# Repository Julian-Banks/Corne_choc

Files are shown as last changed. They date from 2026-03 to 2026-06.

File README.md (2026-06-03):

# Corne Choc — Wireless Build

A wireless, hot-swappable Corne (crkbd) split keyboard built around Kailh Choc V2 switches and the Corne Chocoflan PCB.

## Final Build Spec

| Decision | Choice |
| --- | --- |
| **Layout** | Corne (3×6 + 3 thumb, split) |
| **PCB** | [Corne Chocoflan](https://github.com/ergomechstore/Corne-chocoflan) (wireless, choc-spaced) |
| **Switches** | Kailh Choc V2 Low Profile — White Rain, Black Cloud, Ghost  |
| **Microcontroller** | SuperMini nRF52840 (cheap Nice!Nano-compatible alternative) |
| **Wireless** | Yes (ZMK / nRF52840) |
| **OLED** | Yes — SSD1306 |
| **Hot-swap** | Yes — Kailh Choc sockets |
| **LEDs** | No (skipped to preserve battery on wireless) |
| **Keycaps** | Choc V2 blanks (surprisingly nice quality) |
| **Case** | [Wireless Corne Chocoflan minimal case](https://www.printables.com/model/1020389-wireless-corne-chocoflan-minimal-keyboard-case/files) |

## Guides & References

- **Official Corne Choc docs** — [foostan/crkbd](https://github.com/foostan/crkbd/tree/main/docs/corne-chocolate)
- **Build log inspiration** (V1 caps, no hot-swap) — [Choc Spaced Corne Wireless](https://github.com/rafaeldelboni/buildlogs/blob/main/crkbd-choc-spaced-switch.md)
- **Chocoflan build blog** — [sascha.sh: I built another mechanical keyboard](https://sascha.sh/posts/i-built-another-mechanical-keyboard/)

### Microcontroller notes
- **SuperMini nRF52840** *(chosen)* — cheap (~$3–5 each), well documented for a Chinese alternative. [Reddit overview](https://www.reddit.com/r/ErgoMechKeyboards/comments/16q5b2c/supermini_nrf52840_a_6_nicenano_20_compatible_mcu/) · [Alternatives wiki](https://github.com/joric/nrfmicro/wiki/Alternatives)
- **Nice!Nano** — the standard, well-documented option, but pricey (~$24 each + shipping).

### Switch references
- [Kailh Choc Switch Impressions](https://www.youtube.com/watch?v=mxUqfPf_1B0)
- [Kailh Choc V2 Red Low-Profile Sound Test](https://www.youtube.com/watch?v=VXPfzeLmQ5g)

### Keycap references (alternatives considered)
- [3D-print: Choc Louder keycaps (choc + MX spacing)](https://www.printables.com/model/1066117-choc-louder-keycaps-choc-and-mx-spacing/files)
- [Resin-printed low-profile caps](https://www.thingiverse.com/thing:4862025)

### Case references (alternatives considered)
- [Slim wireless Corne case](https://www.printables.com/model/416378-wireless-corne-case)
- [Carry case with travel box](https://www.printables.com/model/544127-wireless-corne-choc-v2-case-with-travel-box/files)
- [Case with OLED cover (5×3 Typeractive)](https://www.printables.com/model/441819-wireless-corne-case-5x3-typeractive)

## Bill of Materials

### Electrical Parts

| Part | Specific Part | Link | QTY | Notes |
| --- | --- | --- | --- | --- |
| Microcontroller | SuperMini nRF52840 | | 2 | Cheap alternative to the Nice!Nano |
| MCU headers | | [AliExpress](https://www.aliexpress.com/item/32896689725.html) | 10 × 40-pin (400 pins) | |
| PCB | Corne Chocoflan | [repo](https://github.com/ergomechstore/Corne-chocoflan) | 5 pairs | |
| Switches | Kailh Choc V2 Low Profile — White Rain | [AliExpress](https://www.aliexpress.com/item/1005009022408681.html) | 90 | |
| Switches | Kailh Choc V2 Low Profile — Black Cloud | [AliExpress](https://www.aliexpress.com/item/1005009022408681.html) | 90 | |
| Switches | Kailh Choc V2 Low Profile — Ghost | [AliExpress](https://www.aliexpress.com/item/1005007404357477.html) | 90 | |
| Hot-swap sockets | Kailh Choc sockets | [AliExpress](https://www.aliexpress.com/item/1005008954571807.html) | 220 | |
| Keycaps | Choc V2 blanks | [AliExpress](https://www.aliexpress.com/item/1005009100305250.html) | 220 | Nicer quality than expected |
| Diodes | 1N4148W SMD | [AliExpress](https://www.aliexpress.com/item/32921490945.html) | | |
| OLED display | SSD1306 | [AliExpress](https://www.aliexpress.com/item/1005008640132638.html) | 10 | |
| On/off switch | | [AliExpress](https://www.aliexpress.com/item/1005003829889015.html) | 20 | |
| Reset buttons | Momentary push buttons | [AliExpress](https://www.aliexpress.com/item/1005002201965659.html) | 100 | |
| Battery | LiPo 3.7V 120mAh (PH2.0 connector) | [DIY Electronics](https://www.diyelectronics.co.za/store/li-ion-li-po/6707-lipo-battery-37v-120mah-25x24x35mm-1c-1cell-with-ph20-connector.html) | 2 | |

### Mechanical Parts

Driven by the Chocoflan PCB and the minimal case choice.

| Part | Specific Part | Link | QTY | Notes |
| --- | --- | --- | --- | --- |
| Case | Wireless Corne Chocoflan minimal case | [Printables](https://www.printables.com/model/1020389-wireless-corne-chocoflan-minimal-keyboard-case/files) | 1 set | 3D printed |
| Bottom Plate  | See `plate_cut*.dxf` / `.svg` in repo  | | | lazer cut from Aluminimum |
| Switch plate | See `plate_cut*.dxf` / `.svg` in repo  | | | lazer cut from Aluminimum |
| Standoffs + screws | | | | |
| PK-662 tenting stands | | | | |

## Firmware Setup & Configuration

This board runs [ZMK](https://zmk.dev). Firmware is built in the cloud by GitHub Actions — no local toolchain needed. Full guide: [zmk.dev/docs/user-setup](https://zmk.dev/docs/user-setup).

**Setup (once):**
1. Run the ZMK setup script (or `zmk init`) to create your config repo.
2. Choose the keyboard and controller when prompted:
   - **Keyboard / shield:** `Corne`
   - **Board:** `nice_nano_v2` (the SuperMini nRF52840 is nice!nano-compatible)
3. Push the repo to GitHub.

**Configure:**
- Keymap lives in `config/corne.keymap` — edit layers, combos, behaviors here.
- Feature flags live in `config/corne.conf` — e.g. enable the OLED and disable RGB:
  ```ini
  CONFIG_ZMK_DISPLAY=y
  # no underglow / per-key LEDs on this build
  ```

**Build & flash:**
1. `git push` → GitHub Actions builds automatically.
2. Download the `firmware` artifact from the Actions tab — it contains the `.uf2` files (one per half, plus a `settings_reset`).
3. Double-tap reset on a half to enter bootloader, then drag the matching `.uf2` onto the USB drive that appears. Repeat for the other half.

## Credits

- **PCB** — [Corne Chocoflan by ergomechstore](https://github.com/ergomechstore/Corne-chocoflan). The Gerbers and KiCad source in `PCB/` are vendored from this open-source project.
- **Layout** — [Corne (crkbd) by foostan](https://github.com/foostan/crkbd).
- **Case** — [Wireless Corne Chocoflan minimal case](https://www.printables.com/model/1020389-wireless-corne-chocoflan-minimal-keyboard-case/files).

## Repo Contents

- `PCB/` — pointer to the external Corne Chocoflan PCB design (no source vendored).
- `Laser Cutting/` — switch/plate cut files (`.dxf`, `.svg`, `.pdf`).
- `3D Prints/` — case and cover models (`.step`, `.stl`, `.f3d`), including a custom MK2 chassis and carry case explored during design.
- `images/` — build photos.
- `brainstorming.md` — original decision notes and research (kept for history).

## Build Photos

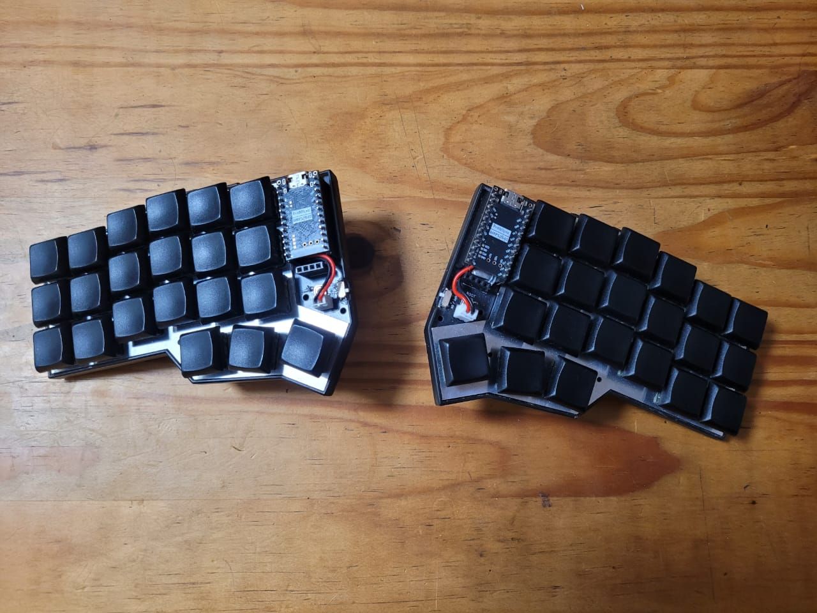
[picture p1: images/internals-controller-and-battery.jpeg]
Internals — controller and battery

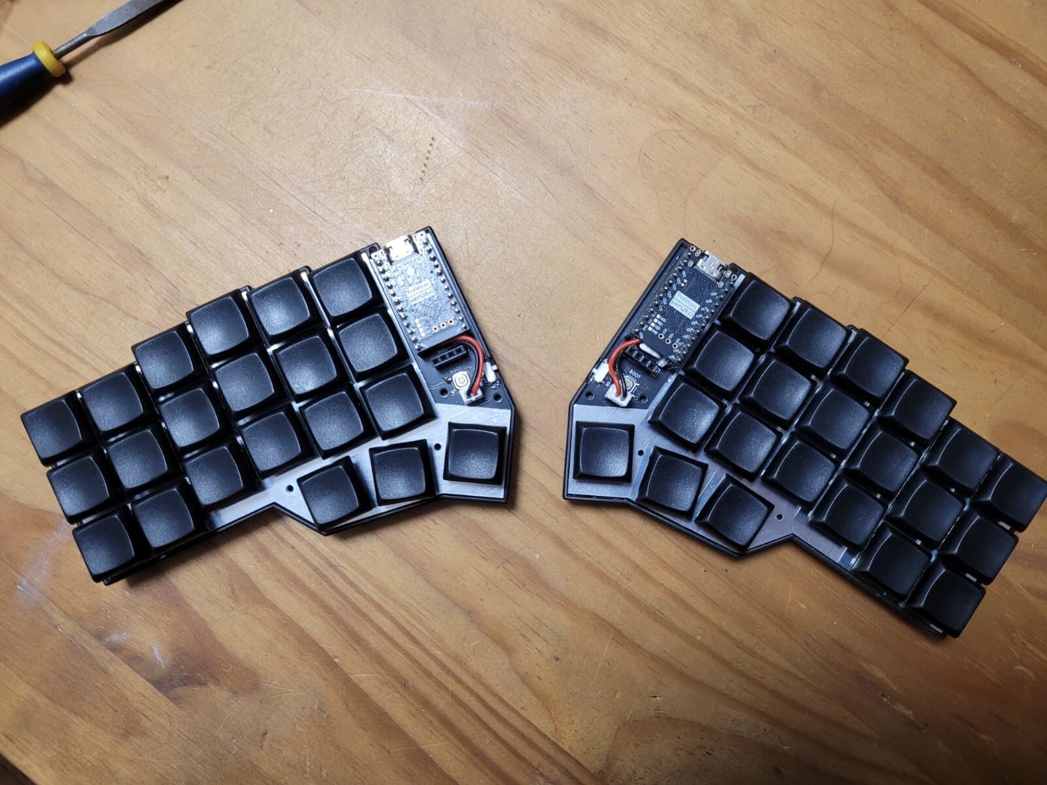
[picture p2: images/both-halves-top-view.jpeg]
Both halves, top view

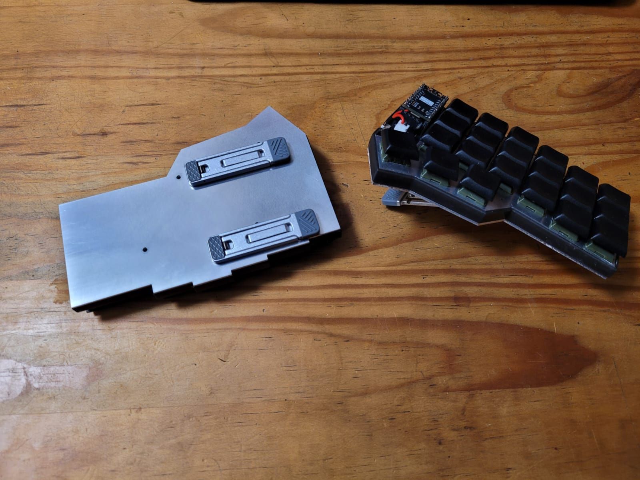
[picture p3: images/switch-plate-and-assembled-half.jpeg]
Switch plate alongside an assembled half

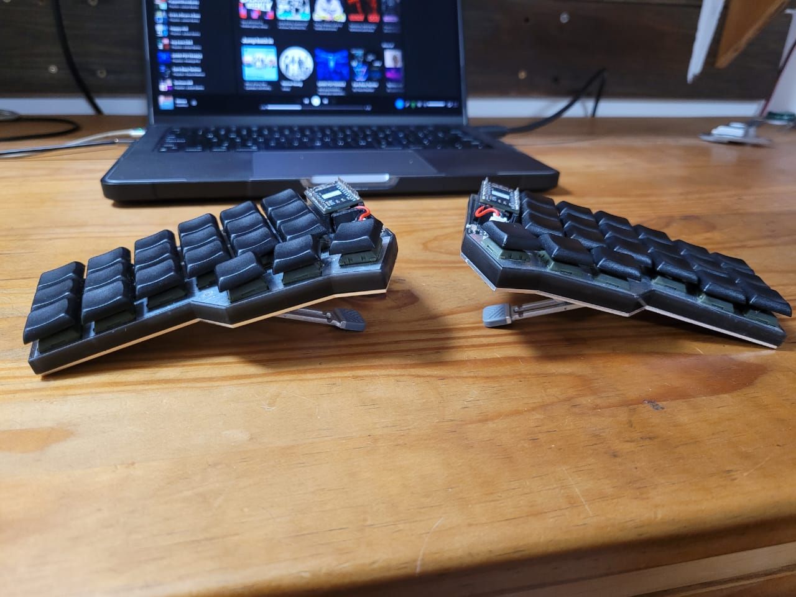
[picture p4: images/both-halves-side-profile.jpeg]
Both halves, side profile

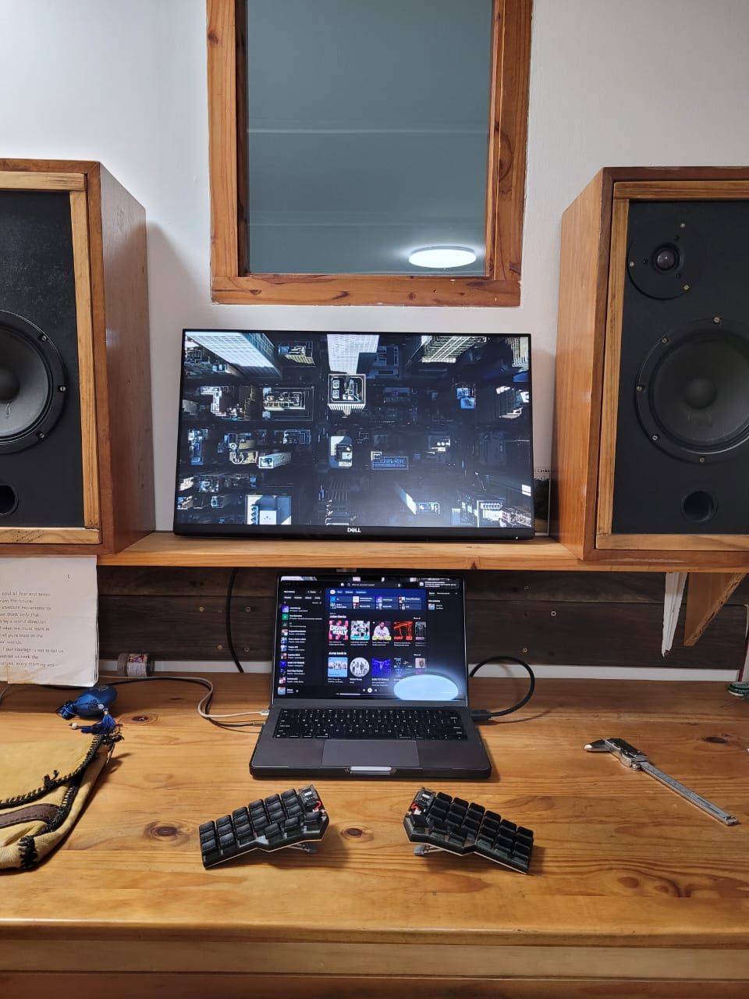
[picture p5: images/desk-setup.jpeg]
Desk setup


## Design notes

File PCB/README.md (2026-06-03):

# PCB

This build uses the **Corne Chocoflan** (rev2) wireless, choc-spaced PCB — the board that was actually fabricated for this keyboard. The design files are vendored here from the upstream open-source repo.

**Credit:** PCB design by [ergomechstore — Corne-chocoflan](https://github.com/ergomechstore/Corne-chocoflan). All design files in this folder originate from that project.

## What's here — `Corne-chocoflan/`

- `gerber/rev2/corne_chocoflan_gerbers.zip` — **production Gerbers** (upload this to JLCPCB / your fab).
- `gerber/rev2/corne_chocoflan_gerbers/` — the unzipped Gerber + drill files.
- `gerber/rev2/bom_pos/` — BOM and pick-and-place (POS) CSVs for assembly.
- `gerber/rev2/ibom.html` — interactive BOM (open in a browser for placement reference).
- `gerber/rev2/corne_chocoflan.step` — 3D model of the board.
- `pcb/rev2/` — KiCad source (`.kicad_pcb`, `.kicad_sch`, `.kicad_pro`) if you need to edit the design.

KiCad auto-save backups and `.git` history from the upstream clone were dropped to keep the repo lean.

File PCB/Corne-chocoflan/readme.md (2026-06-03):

# Corne Chocoflan PCB
An split ergonomic hotswap PCB, based on original Corne made by Foostan. Designed in KiCAD 6.99.

Renders (KiCAD):
**Revision 1**:





**Revision 2**:





## Features
**Revision 1**:
- Uses the Pro Micro and Nice!Nano.
- Uses Kailh Choc hotswap sockets.
- Split ergo layout (see below).
- Physical BOOT button for getting into bootloader.
- Slide switch to turn on and off Bluetooth mode.
- SSD1306 OLED (128x32) and Nice!View E-ink.
- Bonus: Curved traces and teardrops.

**Revision 2**:
- Remove some text on silkscreen.
- Added store logo.
- Move OLED/E-ink connector a bit higher.
- Flip the slide switches from bottom PCB to top PCB.

## Firmware
- This revision of the Corne keyboard is totally compatible with the firmware of the classic corne.

## Layout



Kits and fully built keyboards is available for purchase at https://ergomech.store

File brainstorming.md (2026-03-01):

# Alrighty where to start?

The baseline decisions: 
- **Type**: Corne
- **Switch**: Choc V2 (ghost,white rain, black cloud)
- **PCB**: [Choc spaced Wireless Corne](https://github.com/davidphilipbarr/Choc-Spaced-Corne/tree/main/chocorne-switch)  
- **Leds**: Probably not because we are going wireless
- **Wireless**: Yes 
- **OLED**: Yes 
- **Hotswap sockets**:  Yes
- **Keycaps**: Some cheap blanks

## Guides and docs
Official corne choc docs: [github docs](https://github.com/foostan/crkbd/tree/main/docs/corne-chocolate)

Build Guide inspiration (V1 keycaps, no Hotswap): [Choc Spaced Corne Keyboard - Wireless](https://github.com/rafaeldelboni/buildlogs/blob/main/crkbd-choc-spaced-switch.md)

Blog with Chocoflan board: [some dudes blog](https://sascha.sh/posts/i-built-another-mechanical-keyboard/)

### MicroController

**Nice!Nano** 
- standard option, documented and will work
- spenny ($24 each plus shipping)

**SuperMini NRF52840**
- Cheap! $3-5 each 
- Well documented as far as cheap chinese alternatives go!
- [Supermini nRF52840](https://www.reddit.com/r/ErgoMechKeyboards/comments/16q5b2c/supermini_nrf52840_a_6_nicenano_20_compatible_mcu/)
- [Alternatives (man I love nerd community)](https://github.com/joric/nrfmicro/wiki/Alternatives) 
  
### OLED
Yes just cause it's pretty freaking cool. 

### Switches 
[Kailh Choc Switch Impressions](https://www.youtube.com/watch?v=mxUqfPf_1B0)
[Kailh Choc V2 Red Low-Profile Sound Test](https://www.youtube.com/watch?v=VXPfzeLmQ5g)
I think Red makes sense, most similar to my laptop, I don't like loud keyboards. idk. 
### Keycaps
[3d Print them myself?](https://www.printables.com/model/1066117-choc-louder-keycaps-choc-and-mx-spacing/files)
Low profile and choc spaced
[3d Resin printed](https://www.thingiverse.com/thing:4862025)

### Case 
[Nice slim look](https://www.printables.com/model/416378-wireless-corne-case)

[chocoflan case](https://www.printables.com/model/1020389-wireless-corne-chocoflan-minimal-keyboard-case/files)

[Carry Case, very profess look](https://www.printables.com/model/544127-wireless-corne-choc-v2-case-with-travel-box/files)
[Has an OLED cover](https://www.printables.com/model/441819-wireless-corne-case-5x3-typeractive)

# Rough BOM 

### Electrical Parts

|Part| Specific Part | Link | QTY | Cost | Notes |
| --- | --- | ---  | --- | --- | --- |
|MicroController|  Supermini nRF52840  | |  2 |  86 (plus shipping and tax) | Cheap alternative to the Nice!Nano  |
|MicroController headers| |  [aliexpress](https://www.aliexpress.com/item/32896689725.html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) | 10*40pin = 400pins |  72 | |
|PCB|  corne chocoflan |  [repo](https://github.com/ergomechstore/Corne-chocoflan?tab=readme-ov-file) |  5 pairs | 600?  | |
|Switches|  Kailh Choc V2 Low Profile - White Rain  | [aliexpress](https://www.aliexpress.com/item/1005009022408681.html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) | 90  | 750  | |
|Switches|  Kailh Choc V2 Low Profile - Black Cloud | [aliexpress](https://www.aliexpress.com/item/1005009022408681.html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) | 90  |  750 | |
|Switches|  Kailh Choc V2 Low Profile - Ghost  | [aliexpress](https://www.aliexpress.com/item/1005007404357477.html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) |  90 | 1350  | |
|Hot Swap Sockets|  Kailh Choc sockets | [aliexpress](https://www.aliexpress.com/item/1005008954571807.html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)  | 220  |  212 | |
|Key Caps|  some cheap V2 blanks (I couldn't find PBT) | [aliexpress](https://www.aliexpress.com/item/1005009100305250.html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) |  220 | 450 | |
|Diodes| 1N4148W SMD diodes | [aliexpress](https://www.aliexpress.com/item/32921490945.html) | | | |
|OLED display| SSD1306 | [aliexpress](https://www.aliexpress.com/item/1005008640132638.html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)  | 10  | 240  | |
| On/off switch | |  [aliexpress](https://www.aliexpress.com/item/1005003829889015.html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) |  20 | 75  | |
|Reset Buttons| Momentery push buttons |  [aliexpress](https://www.aliexpress.com/item/1005002201965659.html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) | 100 |  30 | |
|Battery| | [DIY Electronics](https://www.diyelectronics.co.za/store/li-ion-li-po/6707-lipo-battery-37v-120mah-25x24x35mm-1c-1cell-with-ph20-connector.html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) | | 2  |  68 |

### Mechanical Parts
Defined based off what type of PCB I order? 

|Part| Specific Part | Link | QTY | Cost | Notes |
| --- | --- | --- | --- | --- | --- |
| Case | | | | | |
| top Plate| | | | | |
|Switch Plate| | | | | |
|Standoffs + Screws| | | | | |
|Threaded Inserts| | | | | |

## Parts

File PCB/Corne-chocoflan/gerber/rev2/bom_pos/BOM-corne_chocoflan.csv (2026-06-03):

Comment | Designator | Footprint | LCSC
DIP_L | SW1,SW3 | SW_SPDT_PCM12 | C221841
BOOT_Pin_L | SW2,SW4 | SW_SPST_TL3342 | C2886894
1N4148W_L | D1,D10,D11,D12,D13,D14,D15,D16,D17,D18,D19,D2,D20,D21,D22,D23,D24,D25,D26,D27,D28,D29,D3,D30,D31,D32,D33,D34,D35,D36,D37,D38,D39,D4,D40,D41,D42,D5,D6,D7,D8,D9 | D_SOD-123 | C81598

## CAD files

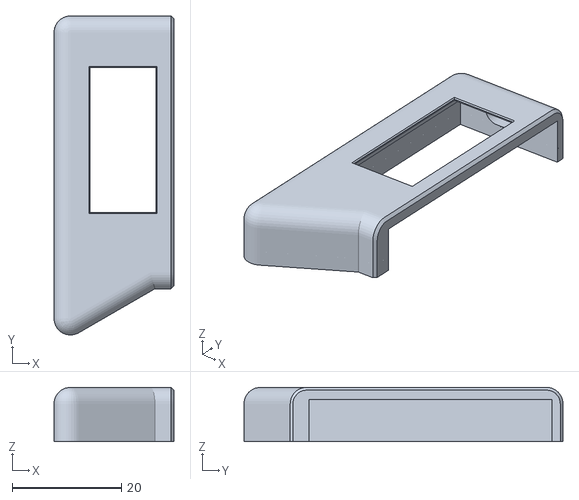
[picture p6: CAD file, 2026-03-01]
3D Prints/screen_cover_holes_fixed_extended.stl
21.9 x 58.3 x 9.90

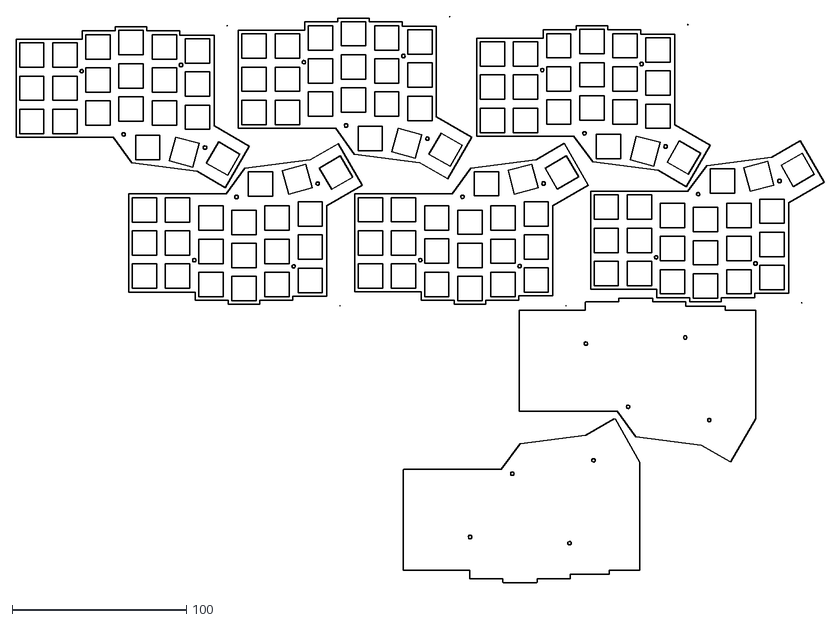
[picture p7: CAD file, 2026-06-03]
Laser Cutting/plate_cut_1.dxf
463.2 x 324.5

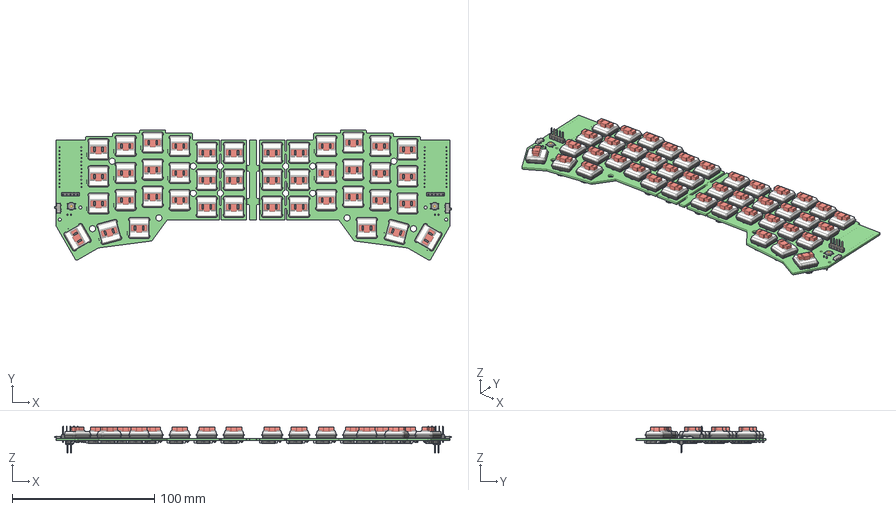
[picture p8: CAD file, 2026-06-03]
PCB/Corne-chocoflan/gerber/rev2/corne_chocoflan.step
278.7 x 91.4 x 18.8 mm
_autosave-corne_chocoflan PCB

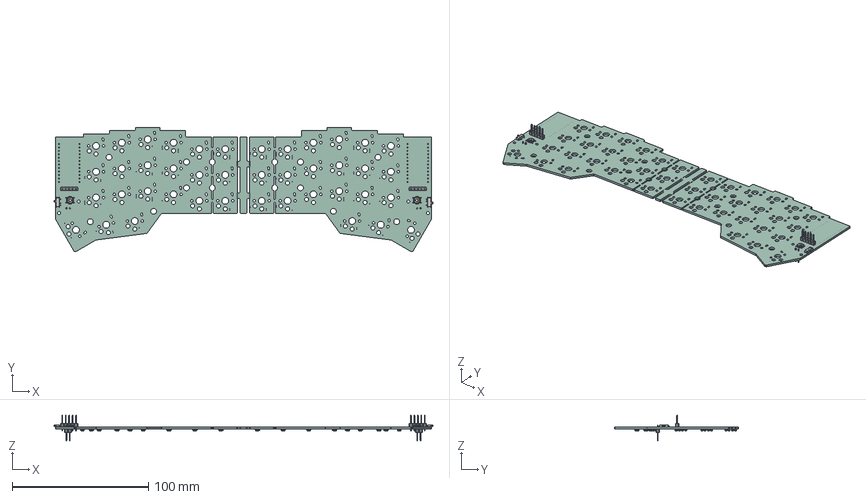
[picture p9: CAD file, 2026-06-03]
PCB/Corne-chocoflan/pcb/rev2/corne_chocoflan.step
278.7 x 91.4 x 18.8 mm
PinHeader_1x05_P2.54mm_Vertical x 2
SW_SPST_TL3342 x 2
SW_SPDT_PCM12 x 2
D_SOD-123 x 42
PinHeader_1x02_P2.54mm_Vertical x 2
corne_chocoflan_PCB

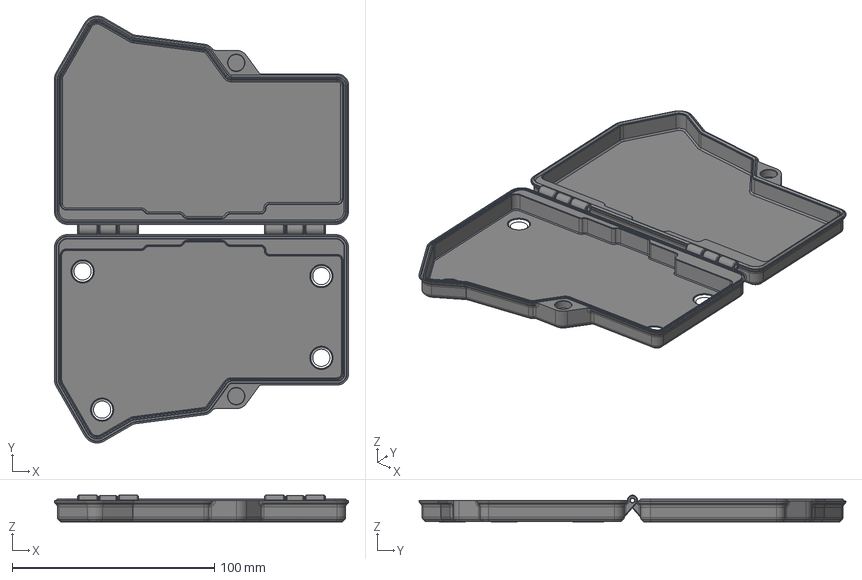
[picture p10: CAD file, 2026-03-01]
3D Prints/Corne Choc Carry Case.step
145.3 x 211.0 x 13.2 mm

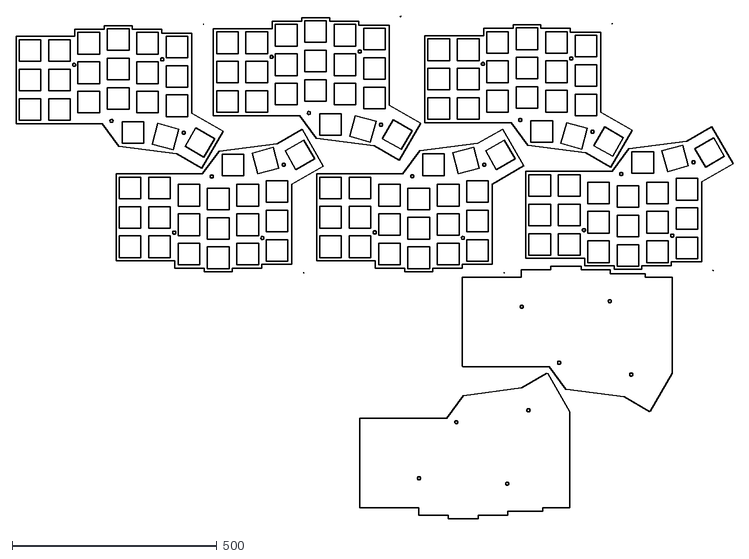
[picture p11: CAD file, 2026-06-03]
Laser Cutting/plate_cut.dxf
1750.5 x 1226.5

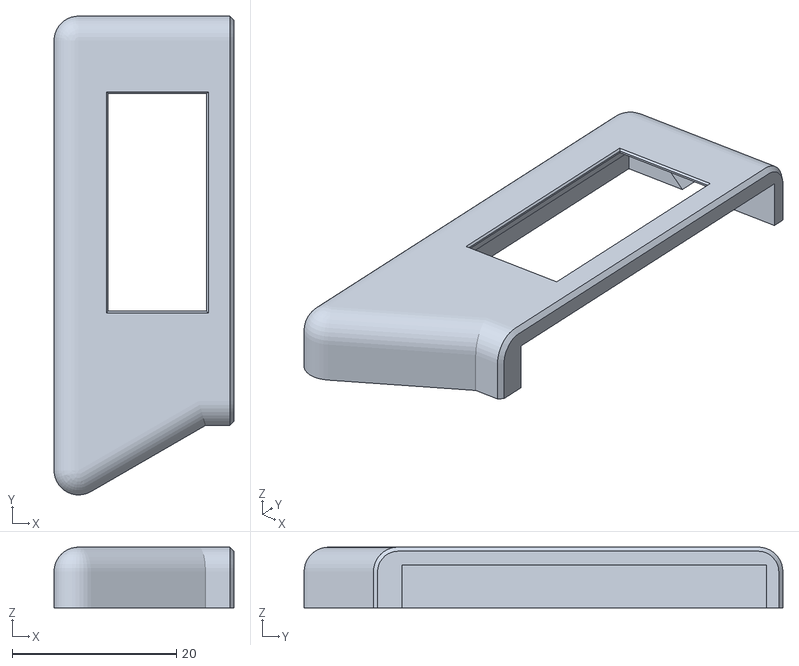
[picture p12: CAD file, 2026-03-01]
3D Prints/screen_cover_holes_fixed.stl
21.9 x 58.3 x 7.40

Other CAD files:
3D Prints/Corne Choc Case (1).f3d

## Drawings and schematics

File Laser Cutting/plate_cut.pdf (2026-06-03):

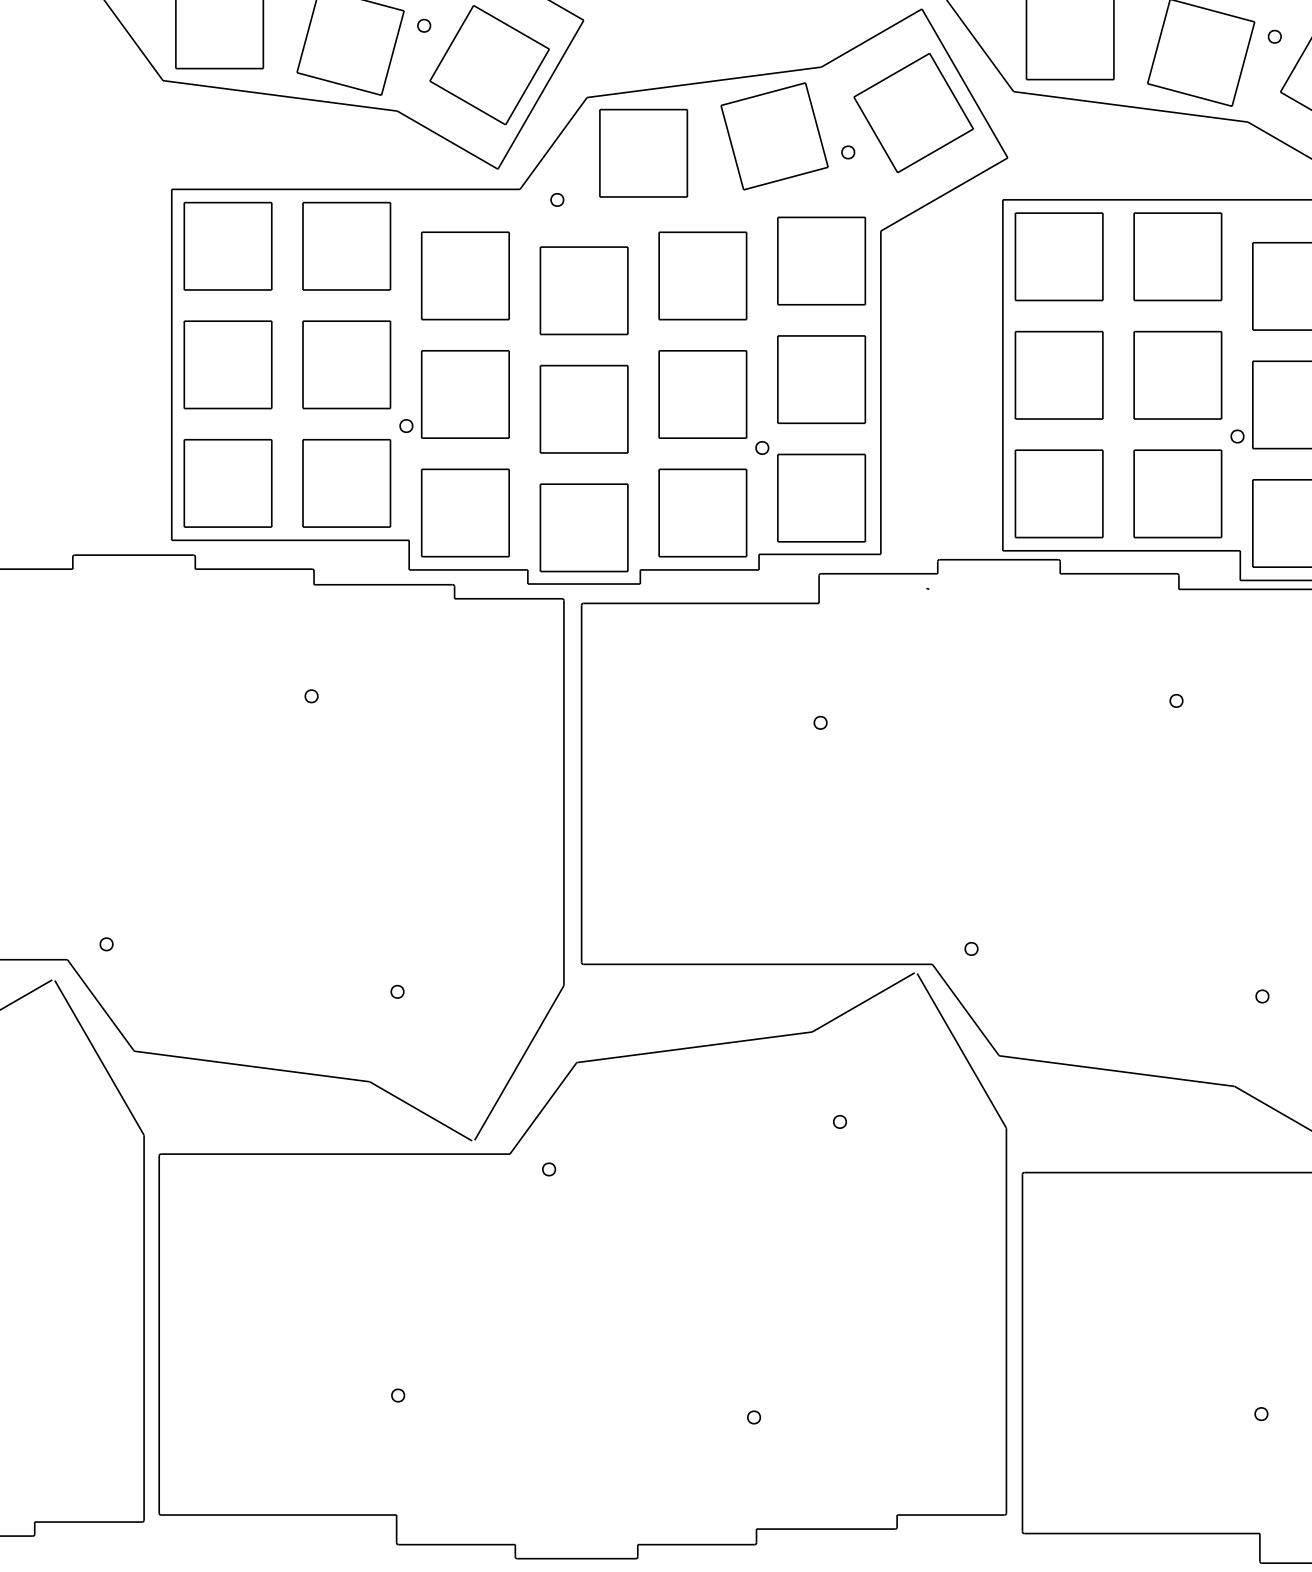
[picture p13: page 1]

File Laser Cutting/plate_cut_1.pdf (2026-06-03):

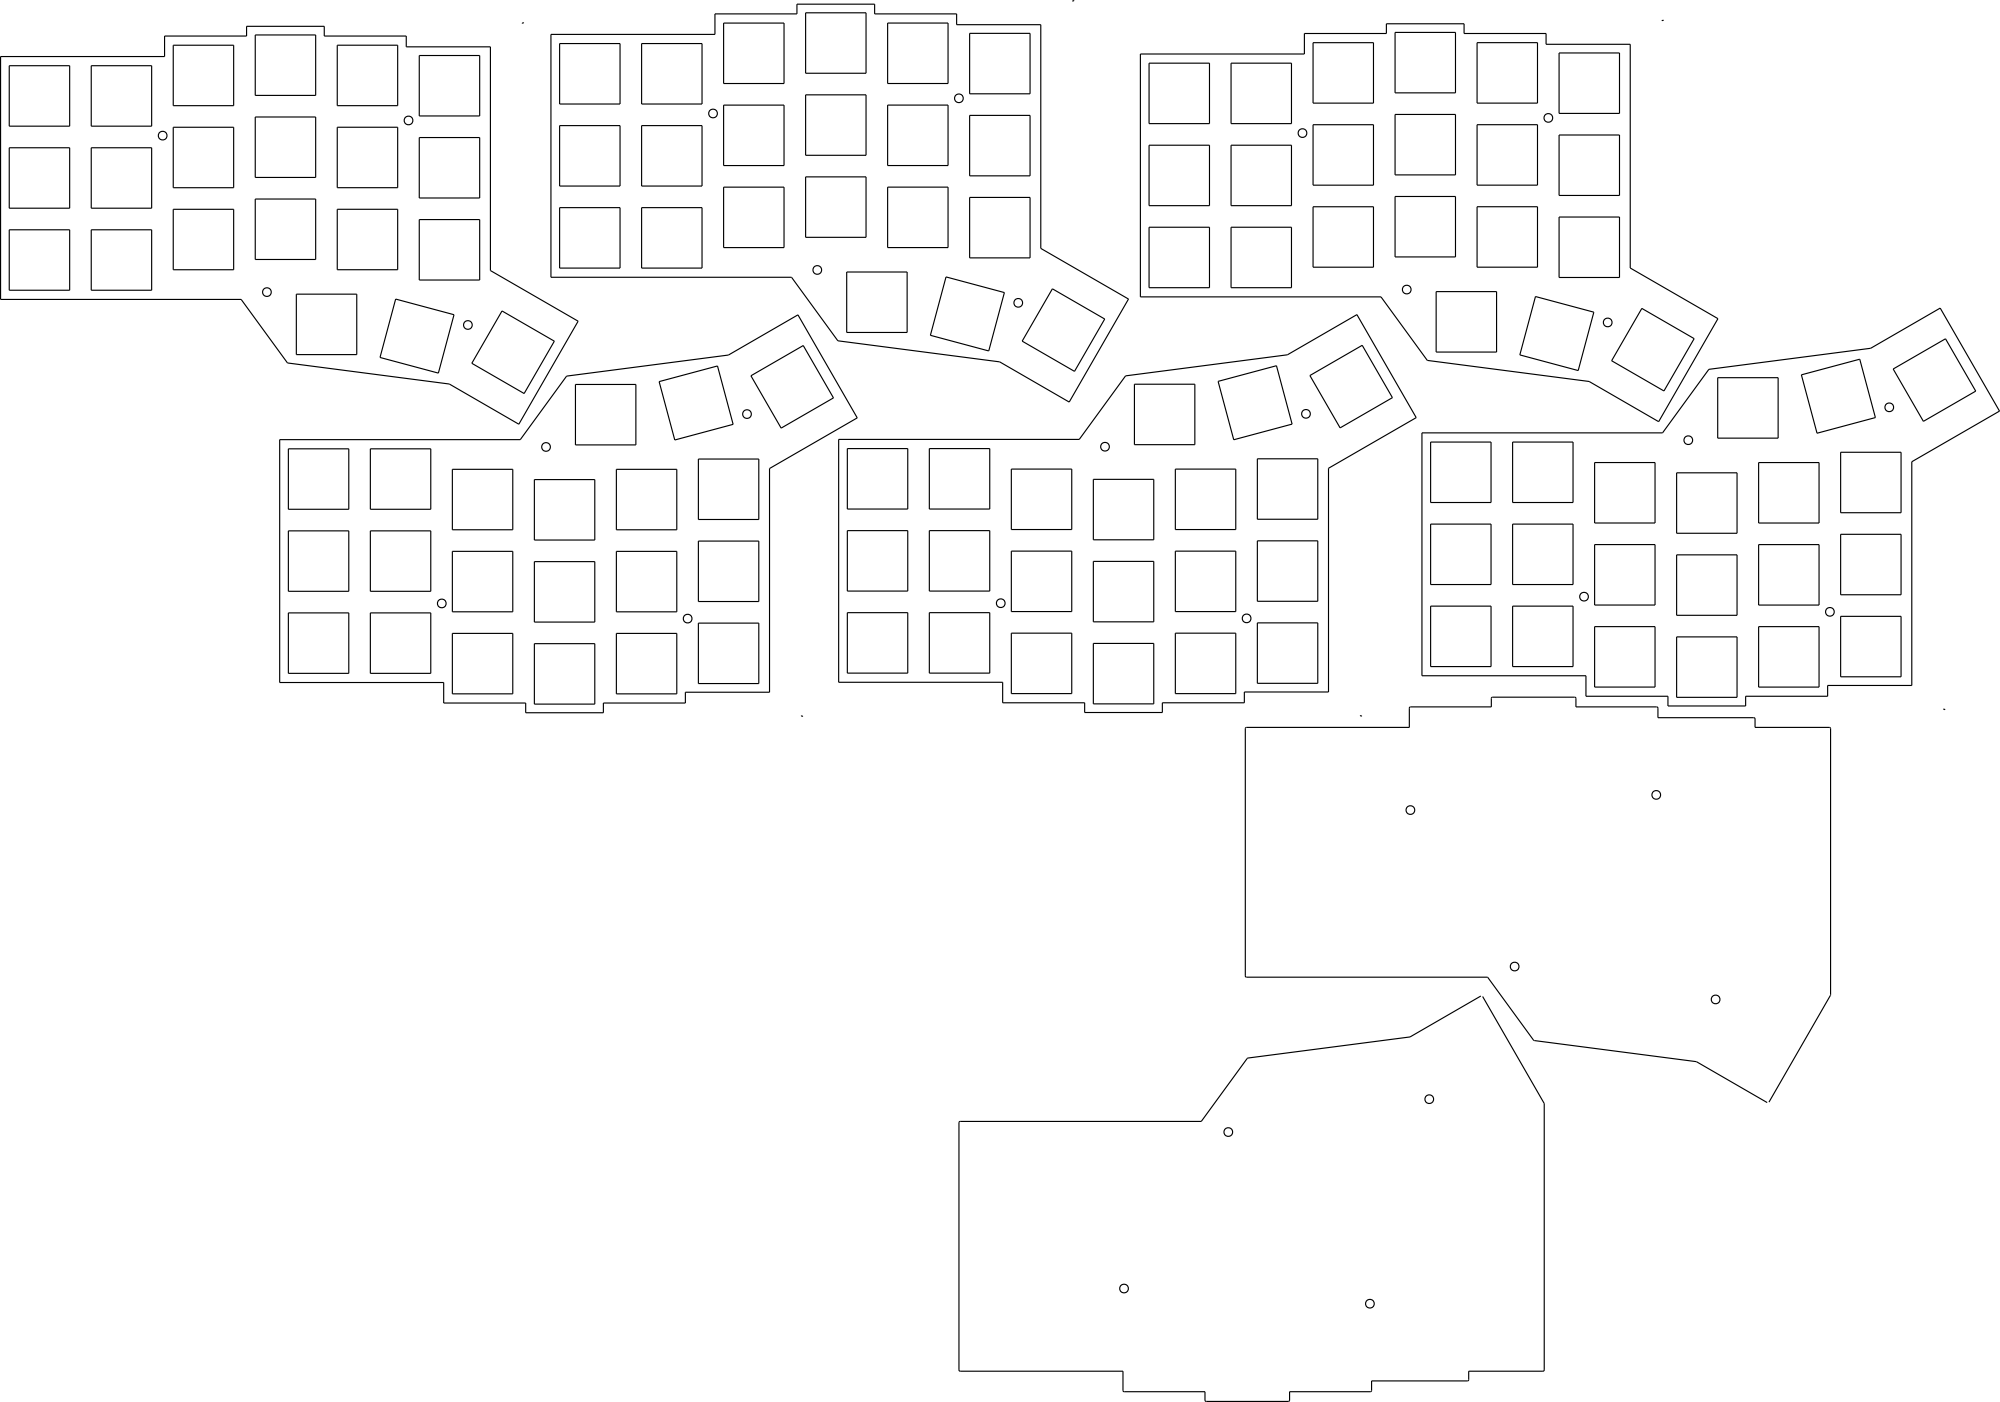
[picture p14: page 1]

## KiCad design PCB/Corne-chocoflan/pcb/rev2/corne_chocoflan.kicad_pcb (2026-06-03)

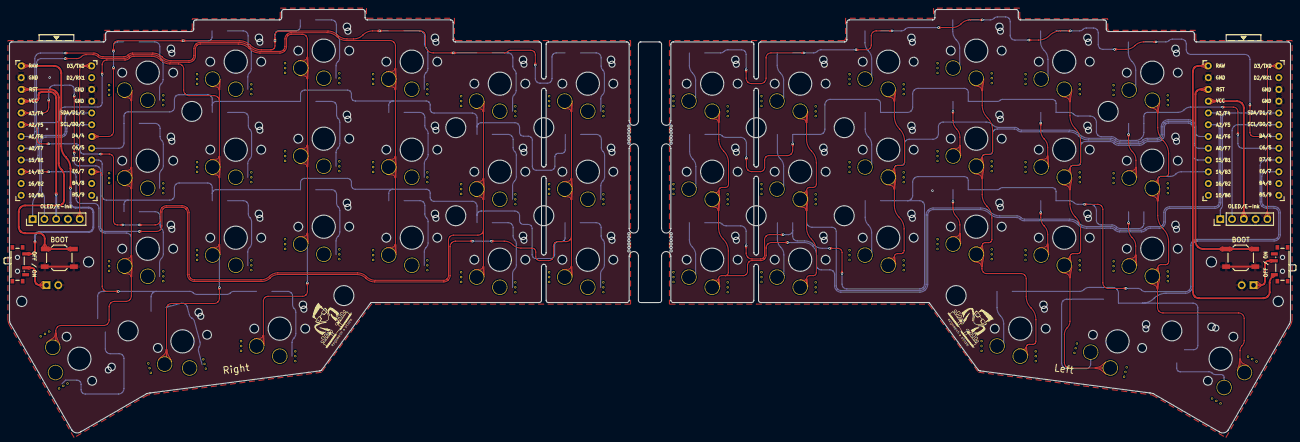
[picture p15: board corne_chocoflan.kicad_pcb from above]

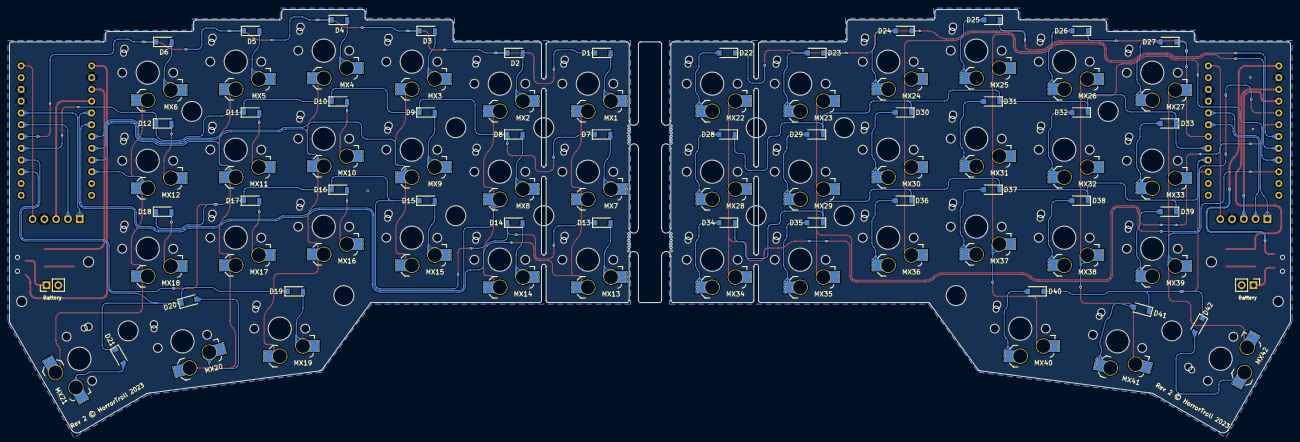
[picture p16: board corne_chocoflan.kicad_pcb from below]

Board: 2 copper layers, 276.5 x 91.4 mm, 116 parts (86 on the bottom side), 78 nets.

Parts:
D1, D2, D3, D4, D5, D6, D7, D8, D9, D10, D11, D12, D13, D14, D15, D16, D17, D18, D19, D20, D21: 1N4148W_L; D_SOD-123
D22, D23, D24, D25, D26, D27, D28, D29, D30, D31, D32, D33, D34, D35, D36, D37, D38, D39, D40, D41, D42: 1N4148W_R; D_SOD-123
J1: OLED/E-Ink_L; PinHeader_1x05_P2.54mm_Vertical
J2: Battery_L; PinHeader_1x02_P2.54mm_Vertical
J3: Battery_R; PinHeader_1x02_P2.54mm_Vertical
J4: OLED/E-Ink_R; PinHeader_1x05_P2.54mm_Vertical
M1, M2, M3, M4: Mouse_Bite; mousebites_2mm_big_width
MX1, MX2, MX3, MX4, MX5, MX6, MX7, MX8, MX9, MX10, MX11, MX12, MX13, MX14, MX15, MX16, MX17, MX18, MX19, MX20: 1u_L; SW_choc_v1_v2_HS_1u_corne
MX21: 1.5u_L; SW_choc_v1_v2_HS_1.5u_corne
MX22, MX23, MX24, MX25, MX26, MX27, MX28, MX29, MX30, MX31, MX32, MX33, MX34, MX35, MX36, MX37, MX38, MX39, MX40, MX41: 1u_R; SW_choc_v1_v2_HS_1u_corne
MX42: 1.5u_R; SW_choc_v1_v2_HS_1.5u_corne
SW1: DIP_L; SW_SPDT_PCM12
SW2: BOOT_Pin_L; SW_SPST_TL3342
SW3: DIP_R; SW_SPDT_PCM12
SW4: BOOT_Pin_R; SW_SPST_TL3342
TH1, TH2, TH3, TH4, TH5, TH6, TH7: Screw_M2_TH_L; M2_HOLE_v2
TH8, TH9: Screw_M2_PCB_L; M2_HOLE_v2_corne_2.2mm
TH10, TH11, TH12, TH13, TH14, TH15, TH16: Screw_M2_TH_R; M2_HOLE_v2
TH17, TH18: Screw_M2_PCB_R; M2_HOLE_v2_corne_2.2mm
U1: ProMicro_L; ProMicro_v3
U2: ProMicro_R; ProMicro_v3

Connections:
+3V3: J4.3, U2.21 (VCC)
BOOT_L: SW2.2, U1.22 (RST)
BOOT_R: SW4.2, U2.22 (RST)
CS_L: J1.5, U1.1 (TX0/D3)
CS_R: J4.5, U2.1 (TX0/D3)
Col0_L: MX1.2, MX7.2, MX13.2, U1.20 (F4/A3)
Col0_R: MX22.1, MX28.1, MX34.1, U2.20 (F4/A3)
Col1_L: MX2.2, MX8.2, MX14.2, U1.19 (F5/A2)
Col1_R: MX23.1, MX29.1, MX35.1, U2.19 (F5/A2)
Col2_L: MX3.2, MX9.2, MX15.2, U1.18 (F6/A1)
Col2_R: MX24.1, MX30.1, MX36.1, U2.18 (F6/A1)
Col3_L: MX4.2, MX10.2, MX16.2, MX19.2, U1.17 (F7/A0)
Col3_R: MX25.1, MX31.1, MX37.1, MX40.1, U2.17 (F7/A0)
Col4_L: MX5.2, MX11.2, MX17.2, MX20.2, U1.16 (B1/15)
Col4_R: MX26.1, MX32.1, MX38.1, MX41.1, U2.16 (B1/15)
Col5_L: MX6.2, MX12.2, MX18.2, MX21.2, U1.15 (B3/14)
Col5_R: MX27.1, MX33.1, MX39.1, MX42.1, U2.15 (B3/14)
GND: J1.4, J2.2, SW2.1, U1.3 (GND), U1.4 (GND), U1.23 (GND)
GNDA: J3.2, J4.4, SW4.1, U2.3 (GND), U2.4 (GND), U2.23 (GND)
unnamed: D1.2 (A), MX1.1
unnamed: D2.2 (A), MX2.1
unnamed: D3.2 (A), MX3.1
unnamed: D4.2 (A), MX4.1
unnamed: D5.2 (A), MX5.1
unnamed: D6.2 (A), MX6.1
unnamed: D7.2 (A), MX7.1
unnamed: D8.2 (A), MX8.1
unnamed: D9.2 (A), MX9.1
unnamed: D10.2 (A), MX10.1
unnamed: D11.2 (A), MX11.1
unnamed: D12.2 (A), MX12.1
unnamed: D13.2 (A), MX13.1
unnamed: D14.2 (A), MX14.1
unnamed: D15.2 (A), MX15.1
unnamed: D16.2 (A), MX16.1
unnamed: D17.2 (A), MX17.1
unnamed: D18.2 (A), MX18.1
unnamed: D19.2 (A), MX19.1
unnamed: D20.2 (A), MX20.1
unnamed: D21.2 (A), MX21.1
unnamed: D22.2 (A), MX22.2
unnamed: D23.2 (A), MX23.2
unnamed: D24.2 (A), MX24.2
unnamed: D25.2 (A), MX25.2
unnamed: D26.2 (A), MX26.2
unnamed: D27.2 (A), MX27.2
unnamed: D28.2 (A), MX28.2
unnamed: D29.2 (A), MX29.2
unnamed: D30.2 (A), MX30.2
unnamed: D31.2 (A), MX31.2
unnamed: D32.2 (A), MX32.2
unnamed: D33.2 (A), MX33.2
unnamed: D34.2 (A), MX34.2
unnamed: D35.2 (A), MX35.2
unnamed: D36.2 (A), MX36.2
unnamed: D37.2 (A), MX37.2
unnamed: D38.2 (A), MX38.2
unnamed: D39.2 (A), MX39.2
unnamed: D40.2 (A), MX40.2
unnamed: D41.2 (A), MX41.2
unnamed: D42.2 (A), MX42.2
unnamed: J2.1, SW1.2 (B)
unnamed: J3.1, SW3.2 (B)
Row0_L: D1.1 (K), D2.1 (K), D3.1 (K), D4.1 (K), D5.1 (K), D6.1 (K), U1.7 (4/D4)
Row0_R: D22.1 (K), D23.1 (K), D24.1 (K), D25.1 (K), D26.1 (K), D27.1 (K), U2.7 (4/D4)
Row1_L: D7.1 (K), D8.1 (K), D9.1 (K), D10.1 (K), D11.1 (K), D12.1 (K), U1.8 (5/C6)
Row1_R: D28.1 (K), D29.1 (K), D30.1 (K), D31.1 (K), D32.1 (K), D33.1 (K), U2.8 (5/C6)
Row2_L: D13.1 (K), D14.1 (K), D15.1 (K), D16.1 (K), D17.1 (K), D18.1 (K), U1.9 (6/D7)
Row2_R: D34.1 (K), D35.1 (K), D36.1 (K), D37.1 (K), D38.1 (K), D39.1 (K), U2.9 (6/D7)
Row3_L: D19.1 (K), D20.1 (K), D21.1 (K), U1.10 (7/E6)
Row3_R: D40.1 (K), D41.1 (K), D42.1 (K), U2.10 (7/E6)
SCL_L: J1.2, U1.6 (3/D0/SCL)
SCL_R: J4.2, U2.6 (3/D0/SCL)
SDA_L: J1.1, U1.5 (2/D1/SDA)
SDA_R: J4.1, U2.5 (2/D1/SDA)
VBAT: SW1.1 (A), U1.24 (RAW)
VBATA: SW3.1 (A), U2.24 (RAW)
VCC: J1.3, U1.21 (VCC)

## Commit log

2026-03-01 some case and cover resources
    [Corne Choc Carry Case.step, Corne Choc Case (1).f3d, Corne Choc Chasis MK2.step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]
2026-06-03 chore: bit old re-organise
    [BOM-corne_chocoflan.csv, Corne Choc Carry Case.step, Corne Choc Case (1).f3d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]

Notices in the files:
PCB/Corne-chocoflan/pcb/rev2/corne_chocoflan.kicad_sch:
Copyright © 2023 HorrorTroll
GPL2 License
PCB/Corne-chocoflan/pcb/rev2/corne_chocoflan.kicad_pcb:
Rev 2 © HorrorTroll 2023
